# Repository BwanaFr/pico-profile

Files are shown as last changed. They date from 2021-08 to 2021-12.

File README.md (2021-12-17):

# pico-profile

This project goal is to emulate a Profile/Widget hard disk.
My ultimate goal is to be able to use this circuit with my Apple Lisa computer.

It's a work in progress and not yet ready for production.

## Demo
A short video showing the project in action is available on [Youtube](https://youtu.be/dQjzqoluw7A)

## Licensing
The final license of this project is not yet determined.
No commercial usage of this project can be made.

## TODO:
- Improve how Apple resets the MCU
- Add buttons to choose the disk image to use
- ~~Add more silkscreen information (power supply polarity...)~~
- Design a 3D printed enclosure
- ~~Fix the 74L280 footprint on PCB~~
- Make a through hole PCB version
- Test it with an Apple III

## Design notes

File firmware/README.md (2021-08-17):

# pico-profile firmware

## Firmware for pico-profile PCB

This firmware is the firmware for pico-profile.
It's a work in progress...

## Dependencies

This project uses pieces of code of the [no-OS-FatFS-SD-SPI-RPi-Pico](https://github.com/carlk3/no-OS-FatFS-SD-SPI-RPi-Pico) library.

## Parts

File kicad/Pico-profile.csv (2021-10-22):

Reference | Value | Footprint | Datasheet
U7 | Pico | MCU_RaspberryPi_and_Boards:RPi_Pico_SMD_TH
U1 | 74LS280 | Package_SO:SO-14_3.9x8.65mm_P1.27mm | http://www.ti.com/lit/gpn/sn74LS280
U2 | 74LS244 | Package_SO:SOIC-20W_7.5x12.8mm_P1.27mm | http://www.ti.com/lit/ds/symlink/sn74ls244.pdf
U3 | 74LVC244 | Package_SO:SOIC-20W_7.5x12.8mm_P1.27mm | http://www.ti.com/lit/ds/symlink/sn74ls244.pdf
U4 | 74LVC2G240 | Package_SO:TSSOP-8_3x3mm_P0.65mm | http://www.ti.com/lit/sg/scyt129e/scyt129e.pdf
C3 | 10uF | Capacitor_SMD:C_0603_1608Metric | ~
C5 | 10uF | Capacitor_SMD:C_0603_1608Metric | ~
C6 | 100nF | Capacitor_SMD:C_0603_1608Metric | ~
J1 | Parallel | Connector_IDC:IDC-Header_2x13_P2.54mm_Vertical | ~
R6 | 100 | Resistor_SMD:R_0603_1608Metric | ~
R7 | 100 | Resistor_SMD:R_0603_1608Metric | ~
R8 | 100 | Resistor_SMD:R_0603_1608Metric | ~
R11 | 100 | Resistor_SMD:R_0603_1608Metric | ~
R12 | 100 | Resistor_SMD:R_0603_1608Metric | ~
R13 | 100 | Resistor_SMD:R_0603_1608Metric | ~
R9 | 100 | Resistor_SMD:R_0603_1608Metric | ~
R10 | 100 | Resistor_SMD:R_0603_1608Metric | ~
J2 | DB25_Female | Connector_Dsub:DSUB-25_Female_Horizontal_P2.77x2.84mm_EdgePinOffset7.70mm_Housed_MountingHolesOffset9.12mm | ~
R2 | 47k | Resistor_SMD:R_0603_1608Metric | ~
J4 | I2C | Connector_PinHeader_2.54mm:PinHeader_1x04_P2.54mm_Vertical | ~
C4 | 10uF | Capacitor_SMD:C_0603_1608Metric | ~
C7 | 100nF | Capacitor_SMD:C_0603_1608Metric | ~
C8 | 100nF | Capacitor_SMD:C_0603_1608Metric | ~
C2 | 100nF | Capacitor_SMD:C_0603_1608Metric | ~
C1 | 100nF | Capacitor_SMD:C_0603_1608Metric | ~
J3 | Micro_SD_Card | Connector_Card:microSD_HC_Molex_104031-0811 | http://katalog.we-online.de/em/datasheet/693072010801.pdf
R3 | 4.7k | Resistor_SMD:R_0603_1608Metric | ~
R4 | 4.7k | Resistor_SMD:R_0603_1608Metric | ~
R5 | 4.7k | Resistor_SMD:R_0603_1608Metric | ~
U8 | 74LVC1G07 | Package_TO_SOT_SMD:SOT-23-5_HandSoldering | http://www.ti.com/lit/sg/scyt129e/scyt129e.pdf
U5 | 74LVC1G04 | Package_TO_SOT_SMD:SOT-23-5_HandSoldering | http://www.ti.com/lit/sg/scyt129e/scyt129e.pdf
R14 | 100 | Resistor_SMD:R_0603_1608Metric | ~
R16 | 100 | Resistor_SMD:R_0603_1608Metric | ~
R17 | 100 | Resistor_SMD:R_0603_1608Metric | ~
R18 | 100 | Resistor_SMD:R_0603_1608Metric | ~
R15 | 100 | Resistor_SMD:R_0603_1608Metric | ~
U6 | 74LVC1G04 | Package_TO_SOT_SMD:SOT-23-5_HandSoldering | http://www.ti.com/lit/sg/scyt129e/scyt129e.pdf
U9 | 74LVC1G04 | Package_TO_SOT_SMD:SOT-23-5_HandSoldering | http://www.ti.com/lit/sg/scyt129e/scyt129e.pdf
R1 | 0 | Resistor_SMD:R_0603_1608Metric | ~
J5 | Screw_Terminal_01x02 | Connector_Phoenix_MSTB:PhoenixContact_MSTBA_2,5_2-G-5,08_1x02_P5.08mm_Horizontal | ~
D1 | MBR1020VL | Diode_SMD:D_SOD-123F | https://www.onsemi.com/pub/Collateral/MBR1020VL-D.PDF
R19 | 10k | Resistor_SMD:R_0603_1608Metric | ~

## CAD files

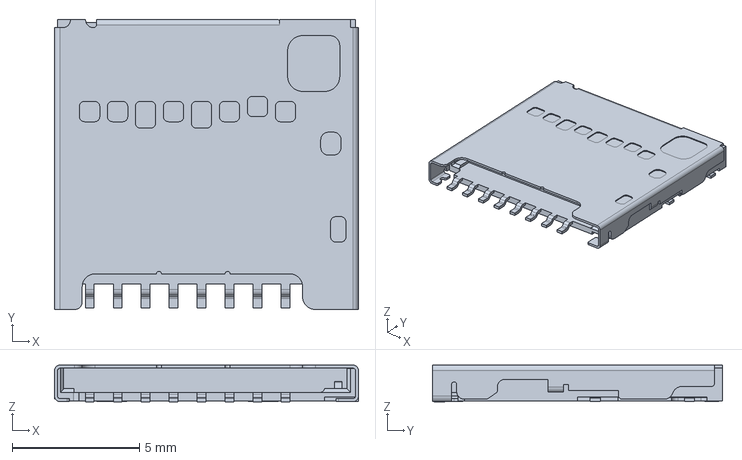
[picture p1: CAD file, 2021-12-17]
kicad/3d/1040310811.step
12.0 x 11.4 x 1.45 mm

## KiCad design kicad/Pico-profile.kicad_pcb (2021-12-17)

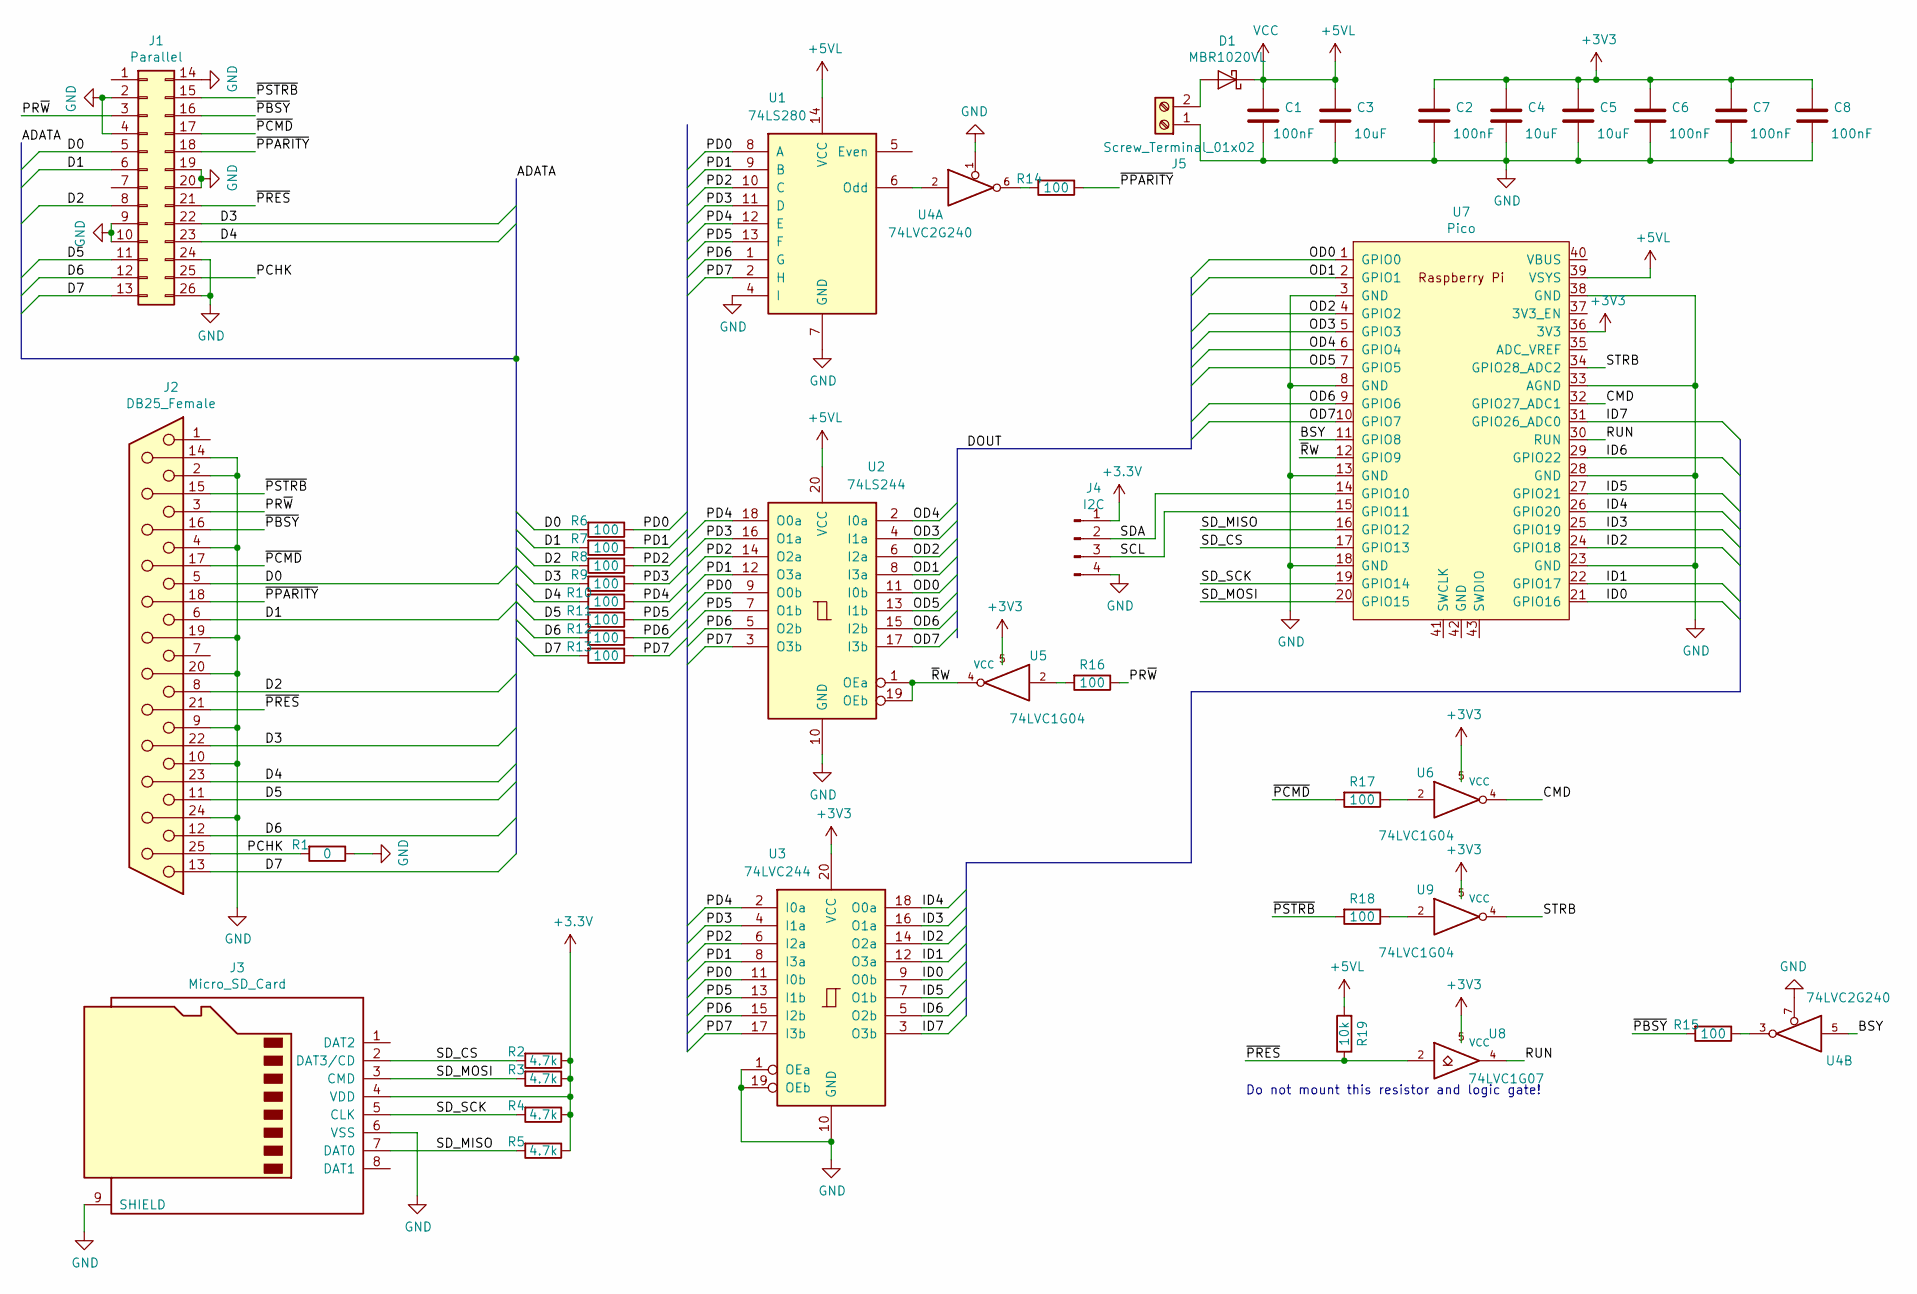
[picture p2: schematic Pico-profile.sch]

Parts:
C1, C2, C6, C7, C8: 100nF; C_0603_1608Metric
C3, C4, C5: 10uF; C_0603_1608Metric
D1: MBR1020VL; D_SOD-123F
J1: Parallel; IDC-Header_2x13_P2.54mm_Vertical
J2: DB25_Female; DSUB-25_Female_Horizontal_P2.77x2.84mm_EdgePinOffset7.70mm_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
J3: Micro_SD_Card; microSD_HC_Molex_104031-0811
J4: I2C; PinHeader_1x04_P2.54mm_Vertical
J5: Screw_Terminal_01x02; PhoenixContact_MSTBA_2,5_2-G-5,08_1x02_P5.08mm_Horizontal
R1: 0; R_0603_1608Metric
R2, R3, R4, R5: 4.7k; R_0603_1608Metric
R6, R7, R8, R9, R10, R11, R12, R13, R14, R15, R16, R17, R18: 100; R_0603_1608Metric
R19: 10k; R_0603_1608Metric
U1: 74LS280; SO-16_5.3x10.2mm_P1.27mm
U2: 74LS244; SOIC-20W_7.5x12.8mm_P1.27mm
U3: 74LVC244; SOIC-20W_7.5x12.8mm_P1.27mm
U4: 74LVC2G240; TSSOP-8_3x3mm_P0.65mm
U5, U6, U9: 74LVC1G04; SOT-23-5_HandSoldering
U7: Pico; RPi_Pico_SMD_TH
U8: 74LVC1G07; SOT-23-5_HandSoldering

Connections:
+5VL: C1.1, C3.1, D1.1 (K), R19.2, U1.14 (VCC), U2.20 (VCC), U4.8 (VCC), U7.39 (VSYS)
/BSY: U4.5, U7.11 (GPIO8)
/CMD: U6.4, U7.32 (GPIO27_ADC1)
/D0: J1.5, J2.5, R6.2
/D1: J1.6, J2.6, R7.2
/D2: J1.8, J2.8, R8.2
/D3: J1.22, J2.22, R9.2
/D4: J1.23, J2.23, R10.2
/D5: J1.11, J2.11, R11.2
/D6: J1.12, J2.12, R12.2
/D7: J1.13, J2.13, R13.2
/ID0: U3.9 (O0b), U7.21 (GPIO16)
/ID1: U3.12 (O3a), U7.22 (GPIO17)
/ID2: U3.14 (O2a), U7.24 (GPIO18)
/ID3: U3.16 (O1a), U7.25 (GPIO19)
/ID4: U3.18 (O0a), U7.26 (GPIO20)
/ID5: U3.7 (O1b), U7.27 (GPIO21)
/ID6: U3.5 (O2b), U7.29 (GPIO22)
/ID7: U3.3 (O3b), U7.31 (GPIO26_ADC0)
/OD0: U2.11 (I0b), U7.1 (GPIO0)
/OD1: U2.8 (I3a), U7.2 (GPIO1)
/OD2: U2.6 (I2a), U7.4 (GPIO2)
/OD3: U2.4 (I1a), U7.5 (GPIO3)
/OD4: U2.2 (I0a), U7.6 (GPIO4)
/OD5: U2.13 (I1b), U7.7 (GPIO5)
/OD6: U2.15 (I2b), U7.9 (GPIO6)
/OD7: U2.17 (I3b), U7.10 (GPIO7)
/PCHK: J1.25, J2.25, R1.2
/PD0: R6.1, U1.8 (A), U2.9 (O0b), U3.11 (I0b)
/PD1: R7.1, U1.9 (B), U2.12 (O3a), U3.8 (I3a)
/PD2: R8.1, U1.10 (C), U2.14 (O2a), U3.6 (I2a)
/PD3: R9.1, U1.11 (D), U2.16 (O1a), U3.4 (I1a)
/PD4: R10.1, U1.12 (E), U2.18 (O0a), U3.2 (I0a)
/PD5: R11.1, U1.13 (F), U2.7 (O1b), U3.13 (I1b)
/PD6: R12.1, U1.1 (G), U2.5 (O2b), U3.15 (I2b)
/PD7: R13.1, U1.2 (H), U2.3 (O3b), U3.17 (I3b)
/PR~W: J1.3, J2.3, R16.1
/RUN: U7.30 (RUN), U8.4
/SCL: J4.3, U7.15 (GPIO11)
/SDA: J4.2, U7.14 (GPIO10)
/SD_CS: J3.2 (DAT3/CD), R2.2, U7.17 (GPIO13)
/SD_MISO: J3.7 (DAT0), R5.2, U7.16 (GPIO12)
/SD_MOSI: J3.3 (CMD), R3.2, U7.20 (GPIO15)
/SD_SCK: J3.5 (CLK), R4.2, U7.19 (GPIO14)
/STRB: U7.34 (GPIO28_ADC2), U9.4
/~PBSY: J1.16, J2.16, R15.2
/~PCMD: J1.17, J2.17, R17.2
/~PPARITY: J1.18, J2.18, R14.1
/~PRES: J1.21, J2.21, R19.1, U8.2
/~PSTRB: J1.15, J2.15, R18.2
/~R~W: U2.1 (OEa), U2.19 (OEb), U5.4, U7.12 (GPIO9)
GND: C1.2, C2.2, C3.2, C4.2, C5.2, C6.2, C7.2, C8.2, J1.2, J1.4, J1.9, J1.10, J1.14, J1.19, J1.20, J1.24, J1.26, J2.2, J2.4, J2.9, J2.10, J2.14, J2.19, J2.20, J2.24, J3.6 (VSS), J3.9 (SHIELD), J4.4, J5.1, R1.1, U1.4 (I), U1.7 (GND), U2.10 (GND), U3.1 (OEa), U3.10 (GND), U3.19 (OEb), U4.1, U4.4 (GND), U4.7, U5.3 (GND), U6.3 (GND), U7.3 (GND), U7.8 (GND), U7.13 (GND), U7.18 (GND), U7.23 (GND), U7.28 (GND), U7.33 (AGND), U7.38 (GND), U8.3 (GND), U9.3 (GND)
unnamed: D1.2 (A), J5.2
unnamed: R14.2, U4.6
unnamed: R15.1, U4.3
unnamed: R16.2, U5.2
unnamed: R17.1, U6.2
unnamed: R18.1, U9.2
unnamed: U1.6 (Odd), U4.2

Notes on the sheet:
Do not mount this resistor and logic gate!

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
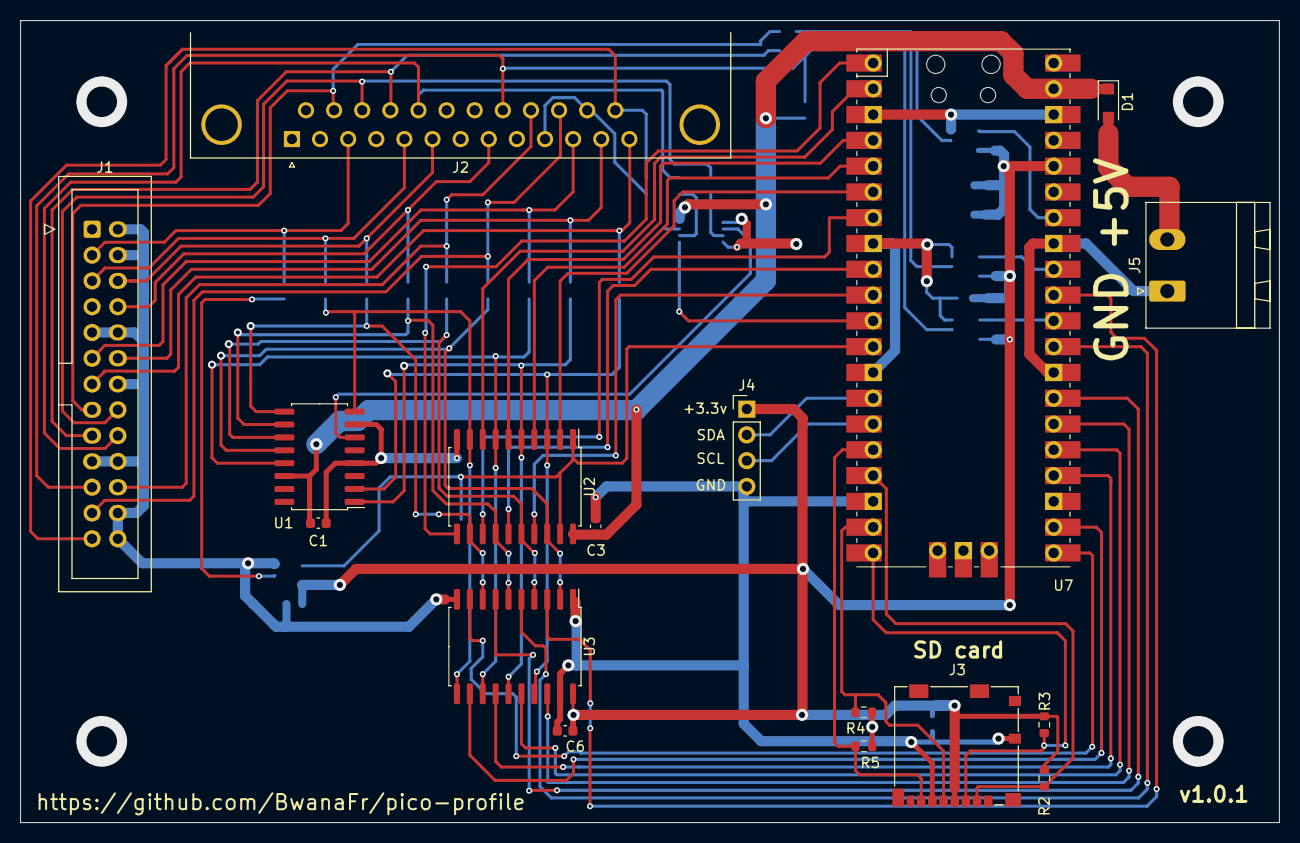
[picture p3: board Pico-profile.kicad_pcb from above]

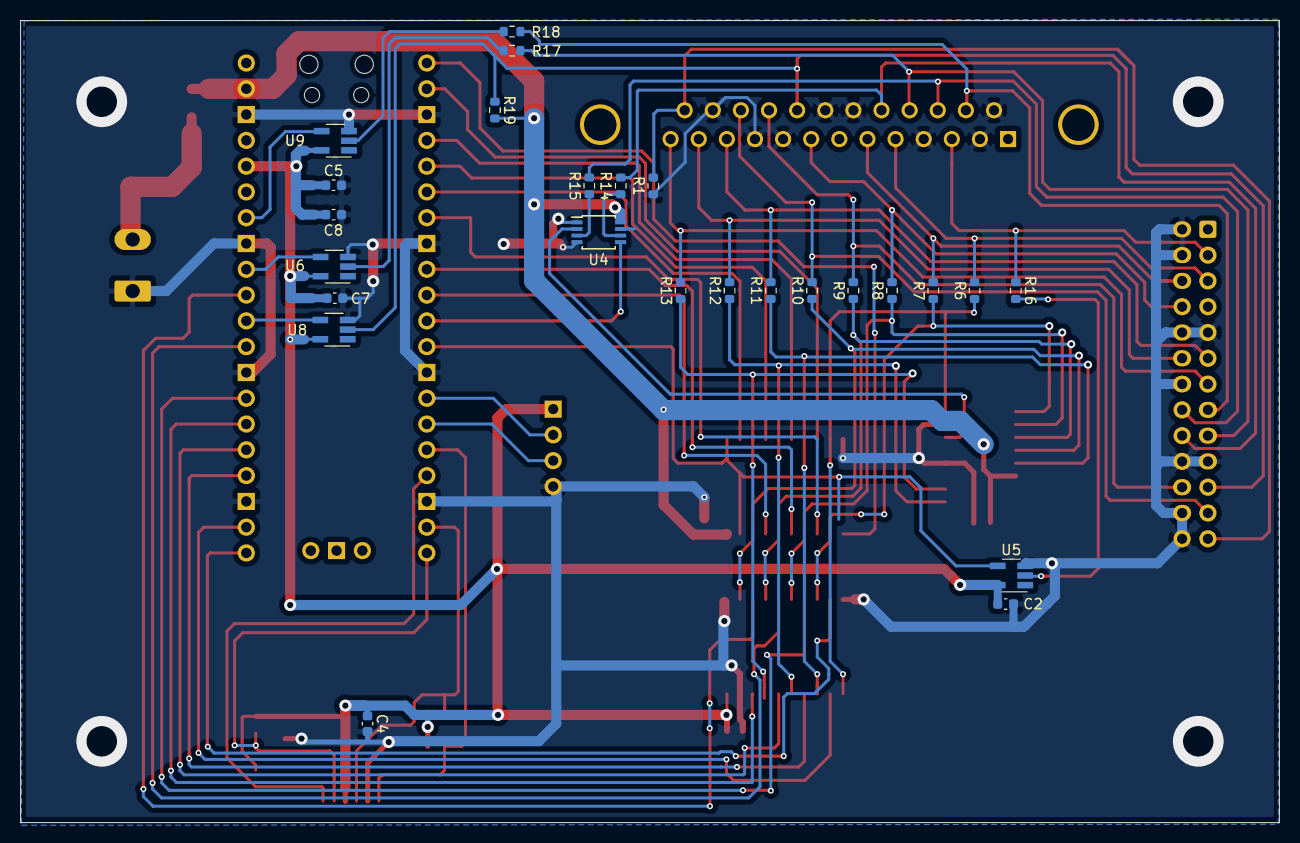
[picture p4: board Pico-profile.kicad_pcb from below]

Board: 2 copper layers, 124.0 x 79.0 mm, 42 parts (25 on the bottom side), 60 nets.

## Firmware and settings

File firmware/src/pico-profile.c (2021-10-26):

#include <stdio.h>
#include "pico/stdlib.h"

#include "pico-profile.pio.h"
#include "io_functions.h"
#include "protocol.h"

#include "ff.h"
#include "sd_card.h"

//PIO for command state machine
#define CMD_PIO pio1
#define CMD_SM 0
uint pio_cmd_offs = 0;
pio_sm_config pio_cmd_cfg = {0,0,0,0};

//FATFS for SD card data exchange
FATFS fs;

/**
 * Mount the SD card
 */
static FRESULT run_mount() {
    char *arg1 = "0:";
    FATFS *p_fs = &fs;
    return f_mount(p_fs, arg1, 1);
}


// static void run_unmount() {
//     char *arg1 = "0:";
//     FRESULT fr = f_unmount(arg1);
//     if (FR_OK != fr) printf("f_mount error: %s (%d)\n", FRESULT_str(fr), fr);
// }

// static void run_mount() {
//     char *arg1 = "0:";
//     FATFS *p_fs = &fs;
//     FRESULT fr = f_mount(p_fs, arg1, 1);
//     if (FR_OK != fr) printf("f_mount error: %s (%d)\n", FRESULT_str(fr), fr);
// }

// static void run_getfree() {
//     char *arg1 = "0:";
//     DWORD fre_clust, fre_sect, tot_sect;
//     /* Get volume information and free clusters of drive */
//     FATFS *p_fs = &fs;
//     FRESULT fr = f_getfree(arg1, &fre_clust, &p_fs);
//     if (FR_OK != fr) {
//         printf("f_getfree error: %s (%d)\n", FRESULT_str(fr), fr);
//         return;
//     }
//     /* Get total sectors and free sectors */
//     tot_sect = (p_fs->n_fatent - 2) * p_fs->csize;
//     fre_sect = fre_clust * p_fs->csize;
//     /* Print the free space (assuming 512 bytes/sector) */
//     printf("%10lu KiB total drive space.\n%10lu KiB available.\n", tot_sect / 2,
//            fre_sect / 2);
// }

// static void run_test_write(){
//     FIL f;
//     FRESULT fr;     /* FatFs return code */
//     char line[10];
//     UINT written;

//     fr = f_open(&f, "message.txt", FA_READ);
//     if(fr){
//         return;
//     }
//     for(int i=0;i<20;++i){
//         sprintf(line, "Line %d\n", (i+1));
//         // f_write(f, strlen(line), )
//     }
// }

// void putToBus(uint8_t data){     
//     gpio_put(OD0, (data & 0x1) == 1);
//     gpio_put(OD1, (((data>>1) & 0x1) == 1));
//     gpio_put(OD2, (((data>>2) & 0x1) == 1));
//     gpio_put(OD3, (((data>>3) & 0x1) == 1));
//     gpio_put(OD4, (((data>>4) & 0x1) == 1));
//     gpio_put(OD5, (((data>>5) & 0x1) == 1));
//     gpio_put(OD6, (((data>>6) & 0x1) == 1));
//     gpio_put(OD7, (((data>>7) & 0x1) == 1));
// }

// uint8_t getBus(){
//     uint8_t ret = 0;
//     uint32_t input = gpio_get_all();
//     ret = (input >> 16) & 0x7F;
//     if(((input >> 26) & 0x1) != 0x0){
//         ret |= 0x80;
//     }
//     return ret;
// }

/**
 * Utility to print command details to serial
 */
void printCommand(uint8_t *cmd){
    uint32_t block = cmd[0] | (cmd[1] << 8) | (cmd[2] << 16);
    switch (cmd[0])
    {
    case READ_CMD:
        printf("Read block $%lx, retries:%u, spare threshold:%u\n", block, cmd[4], cmd[5]);
        break;
    case WRITE_CMD:
        printf("Write block $%lx\n", block);
        break;
    case WRITE_VERIFY_CMD:
        printf("Write & verify block $%lx, retries:%u, spare threshold:%u\n", block, cmd[4], cmd[5]);
        break;
    case WRITE_SPARE:
        printf("Write & Force Sparing block $%lx\n", block);
        break;
    default:
        printf("Unsupported command\n");
        break;
    }
    
}

/**
 * Convert GPIO from state machines to data byte
 */
uint8_t gpioToByte(uint32_t value) {
    return (value & 0x7F) | ((value >> 3) & 0x80);
}

/**
 * Handle commands sent by the Apple
 */
void handleCommand() {
    uint8_t cmd[6];
    printf("Waiting for command\n");
    uint8_t q = gpioToByte(pio_sm_get_blocking(CMD_PIO, CMD_SM));
    if(q != 0x55){
        //Error, Apple must reply with 0x55
        printf("ERROR : Bad acknowledge read");
        pio_sm_restart(CMD_PIO, CMD_SM);
        return;
    }
    //Accept command
    pio_sm_put_blocking(CMD_PIO, CMD_SM, 0x1);
    for(int i=0;i<6;++i){
        cmd[i] = gpioToByte(pio_sm_get_blocking(CMD_PIO, CMD_SM));
    }
    //Accept command, answer 2
    pio_sm_put_blocking(CMD_PIO, CMD_SM, 0x2);
    //Gets the 0x55 ack
    q = gpioToByte(pio_sm_get_blocking(CMD_PIO, CMD_SM));
    if(q != 0x55){
        //Error, Apple must reply with 0x55
        printf("ERROR : Bad acknowledge read");
        pio_sm_restart(CMD_PIO, CMD_SM);
        return;
    }
    if(cmd[0] == 0x0){
        //Reset the state machine
        pio_sm_put_blocking(CMD_PIO, CMD_SM, 0x0);
    }else{
        //Continue with the state machine
        pio_sm_put_blocking(CMD_PIO, CMD_SM, 0x01);
        q = gpioToByte(pio_sm_get_blocking(CMD_PIO, CMD_SM));
        pio_sm_put_blocking(CMD_PIO, CMD_SM, 0x0);
    }
    printCommand(cmd);
}

static void isr() {
    printf(".\n");
    pio_interrupt_clear(CMD_PIO, 0);
}

int main() {
    stdio_init_all();
    initializeGPIO();
    gpio_init(LED_PIN);
    gpio_set_dir(LED_PIN, GPIO_OUT);
    printf("Pico-profile\n");
    //Initialize the command state machine
    //pio_cmd_offs = pio_add_program(CMD_PIO, &pico_profile_cmd_program);
    //pio_cmd_cfg = pico_profile_cmd_pio_init(CMD_PIO, CMD_SM, pio_cmd_offs);
    //Cmd handshake
    pio_cmd_offs = pio_add_program(CMD_PIO, &pico_profile_cmd_hchk_program);
    pio_cmd_cfg = pico_profile_cmd_hchk_pio_init(CMD_PIO, CMD_SM, pio_cmd_offs);
    /*irq_set_exclusive_handler(PIO1_IRQ_0, isr);
    irq_set_enabled(PIO1_IRQ_0, true);
    pio_set_irq0_source_enabled(CMD_PIO, pis_interrupt0, true);*/

    uint8_t i = 0;
    gpio_put(LED_PIN, false);
    while (true) {
        gpio_put(LED_PIN, !gpio_get(LED_PIN));
        sleep_us(500000);
        pio_sm_put_blocking(CMD_PIO, CMD_SM, ++i);
        printf("Response : %x\n", gpioToByte(pio_sm_get_blocking(CMD_PIO, CMD_SM)));
        sleep_us(5000000);
        printf("Command done");
        pio_sm_exec(CMD_PIO, CMD_SM, pio_encode_set(pio_x, 1));
    }
    return 0;
}

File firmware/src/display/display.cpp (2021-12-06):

#include "display.hxx"
#include <stdio.h>
#include <string.h>
#include <pico/stdlib.h>
#include "hardware/i2c.h"
#include "hardware/dma.h"
#include "hardware/irq.h"

#include "lisa_logo.h"
#include "../version.hxx"
#include "font_5x8.hxx"

#define OLED_I2C i2c1

#ifdef WITH_DMA
bool Display::displayAddressed_ = false;             //!< Flag to know if display is addressed
uint16_t Display::frameBuffer_[FRAME_BUFFER_LEN];     //!< Buffer for DMA (use 16 bits for the stop)
uint16_t Display::cmdBuffer_[CMD_BUFFER_LEN] = {0x80, OLED_SET_COL_ADDR,
                                    0x80, 0,
                                    0x80, OLED_WIDTH - 1,
                                    0x80, OLED_SET_PAGE_ADDR,
                                    0x80, 0,
                                    0x80, OLED_NUM_PAGES | (bool_to_bit(true)<<I2C_IC_DATA_CMD_STOP_LSB)
                                    };
int Display::dmaChan_ = -1;
#endif
Display::LineData Display::lines_[2];
bool Display::textMode_ = false;
bool Display::displayOn_ = false;
uint8_t Display::contrast_ = 0;
absolute_time_t Display::nextScroll_;

void Display::configureI2C()
{    
    gpio_set_pulls(SCL_PIN, true, false);
    gpio_set_slew_rate(SCL_PIN, GPIO_SLEW_RATE_SLOW);
    gpio_set_input_hysteresis_enabled(SCL_PIN, true);
    gpio_set_function(SCL_PIN, gpio_function::GPIO_FUNC_I2C);
    
    gpio_set_pulls(SDA_PIN, true, false);
    gpio_set_slew_rate(SDA_PIN, GPIO_SLEW_RATE_SLOW);
    gpio_set_input_hysteresis_enabled(SDA_PIN, true);
    gpio_set_function(SDA_PIN, gpio_function::GPIO_FUNC_I2C);
    i2c_init(OLED_I2C, BAUD_RATE);
}

void Display::sendCmd(uint8_t cmd)
{
    uint8_t buf[2] = {0x80, cmd};
    i2c_write_blocking(OLED_I2C, (OLED_ADDR & OLED_WRITE_MODE), buf, 2, false);
}

#ifdef WITH_DMA
void Display::dmaDone()
{
    //DMA transfer done
    if(dma_channel_get_irq1_status(dmaChan_)){
        dma_channel_acknowledge_irq1(dmaChan_);
        while(!(i2c_get_hw(OLED_I2C)->raw_intr_stat & I2C_IC_RAW_INTR_STAT_STOP_DET_BITS)){
            tight_loop_contents();
        }        
        if(!displayAddressed_){
            displayAddressed_ = true;
            sendBuffer();
        }else{
            displayAddressed_ = false;
        }
    }
}

void Display::sendBuffer()
{
    //Waits for previous DMA transfer to be completed
    while((dmaChan_ != -1) && dma_channel_is_busy(dmaChan_))
        tight_loop_contents();
    //Prepare the I2C/DMA for addressing   
    i2c_get_hw(OLED_I2C)->enable = 0;
    i2c_get_hw(OLED_I2C)->tar = (OLED_ADDR & OLED_WRITE_MODE);
    i2c_get_hw(OLED_I2C)->enable = 1;
    if(dmaChan_ == -1) {
        dmaChan_ = dma_claim_unused_channel(true);
        irq_add_shared_handler(DMA_IRQ_1, Display::dmaDone, PICO_SHARED_IRQ_HANDLER_DEFAULT_ORDER_PRIORITY );       //Set IRQ handler for DMA transfer
        irq_set_enabled(DMA_IRQ_1, true);                          //Enable IRQ
        dma_channel_set_irq1_enabled(dmaChan_, true);
    }
    //Prepare the DMA transfer
    dma_channel_config c = dma_channel_get_default_config(dmaChan_);
    channel_config_set_read_increment(&c, true);
    channel_config_set_write_increment(&c, false);
    channel_config_set_transfer_data_size(&c, DMA_SIZE_16);
    channel_config_set_dreq(&c, i2c_get_dreq(OLED_I2C, true));
    if(!displayAddressed_){
        //Configure channel to transmit adressing commands
        dma_channel_configure(
            dmaChan_,
            &c,
            &i2c_get_hw(OLED_I2C)->data_cmd,    // Destination pointer
            cmdBuffer_,                         // Source pointer
            12,                                 // Number of transfers
            true                                // Start
        );
    }else{
        //Configure channel to data adressing commands
        dma_channel_configure(
            dmaChan_,
            &c,
            &i2c_get_hw(OLED_I2C)->data_cmd,    // Destination pointer
            frameBuffer_,                       // Source pointer
            FRAME_BUFFER_LEN,                   // Number of transfers
            true                                // Start
        );
    }    
}
#endif

void Display::initialize()
{
    configureI2C();

    setDisplayOn(false);    // set display off

    /* memory mapping */
    sendCmd(OLED_SET_MEM_ADDR); // set memory address mode
    sendCmd(0x00); // horizontal addressing mode

    /* resolution and layout */
    sendCmd(OLED_SET_DISP_START_LINE); // set display start line to 0

    sendCmd(OLED_SET_SEG_REMAP | 0x01); // set segment re-map
    // column address 127 is mapped to SEG0

    sendCmd(OLED_SET_MUX_RATIO); // set multiplex ratio
    sendCmd(OLED_HEIGHT - 1); // our display is only 32 pixels high

    sendCmd(OLED_SET_COM_OUT_DIR | 0x08); // set COM (common) output scan direction
    // scan from bottom up, COM[N-1] to COM0

    sendCmd(OLED_SET_DISP_OFFSET); // set display offset
    sendCmd(0x00); // no offset

    sendCmd(OLED_SET_COM_PIN_CFG); // set COM (common) pins hardware configuration
    sendCmd(0x02); // manufacturer magic number

    /* timing and driving scheme */
    sendCmd(OLED_SET_DISP_CLK_DIV); // set display clock divide ratio
    sendCmd(0x80); // div ratio of 1, standard freq

    sendCmd(OLED_SET_PRECHARGE); // set pre-charge period
    sendCmd(0xF1); // Vcc internally generated on our board

    sendCmd(OLED_SET_VCOM_DESEL); // set VCOMH deselect level
    sendCmd(0x30); // 0.83xVcc

    /* display */
    setDisplayContrast(0xFF);   //Set contrast to maximum

    sendCmd(OLED_SET_ENTIRE_ON); // set entire display on to follow RAM content

    sendCmd(OLED_SET_NORM_INV); // set normal (not inverted) display

    sendCmd(OLED_SET_CHARGE_PUMP); // set charge pump
    sendCmd(0x14); // Vcc internally generated on our board

    sendCmd(OLED_SET_SCROLL | 0x00); // deactivate horizontal scrolling if set
    // this is necessary as memory writes will corrupt if scrolling was enabled

    setDisplayOn();     // turn display on

    nextScroll_ = make_timeout_time_ms(SCROLL_SPEED);
}
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

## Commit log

2021-08-17 Initial commit. Still in development
    [Pico-profile.kicad_pcb, Pico-profile.sch]
2021-08-25 Intermediate commit. Worked on hardware
    [Pico-profile.csv, Pico-profile.kicad_pcb, Pico-profile.sch]
2021-08-26 Hardware first revision. Need cosmetic changes
    [Pico-profile.csv, Pico-profile.kicad_pcb, Pico-profile.sch]
2021-08-27 Cosmetic changes on PCB
    [Pico-profile.kicad_pcb, Pico-profile.sch]
2021-08-27 Moved custom libs to project
    [Pico-profile.kicad_pcb]
2021-08-27 Added gerbers for prototype production
    [Pico-profile-B_Cu.gbr, Pico-profile-B_Mask.gbr, Pico-profile-B_Paste.gbr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]
2021-10-22 Started implementing the tester
    [Pico-profile.csv, Pico-profile.sch]
2021-11-08 Moved to DMA
2021-11-09 Removed printf
2021-11-10 Fixed the read state machine
    [io_pins.cpp, io_pins.h, main.cpp]
2021-11-16 Reworked state machines for handling unexpected commands
    [main.cpp, protocol.cpp]
2021-11-25 Fixed minor display issues
    [display.cpp, protocol.cpp]
2021-12-17 Fixed PCB footprint. Added more silkscreen information.
    [1040310811.step, Pico-profile.kicad_pcb, Pico-profile.sch]

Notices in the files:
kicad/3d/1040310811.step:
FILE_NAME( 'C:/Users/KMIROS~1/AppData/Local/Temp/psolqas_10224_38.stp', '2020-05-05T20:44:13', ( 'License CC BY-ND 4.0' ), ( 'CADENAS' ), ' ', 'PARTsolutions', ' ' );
